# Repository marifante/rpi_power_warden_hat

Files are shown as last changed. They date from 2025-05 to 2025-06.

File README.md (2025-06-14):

# Raspberry Pi Warden Hat

This repository contains the kicad project of Power Warden HAT.

   <div align="center">
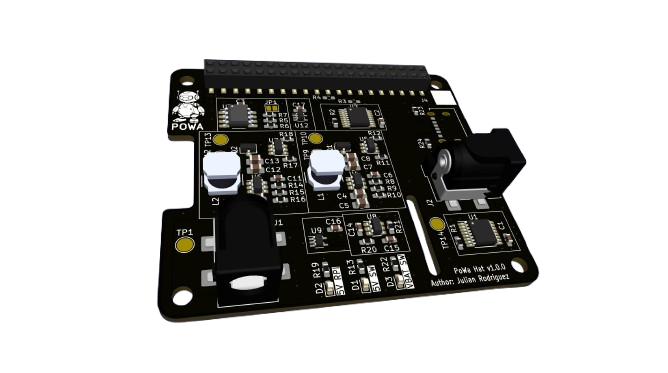
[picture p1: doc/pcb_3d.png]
Power Warden HAT
     
   </div>

## Board description

The HAT is designed to be used with a Raspberry Pi to monitor and control power domains.
It features:

- An individual 5 V power domain.
- An VBAT power domain.
- A dedicated 5 V power supply for the Raspberry Pi.
- An EEPROM to store the HAT configuration.

## Power domains

Each power domain is equipped with a current sensor and an enable input.
The enable input is routed directly to some Raspberry Pi GPIO, allowing the user to control the state of the power domain.
Besides that, the enable input is also controlled by the current sensor, which can disable the power domain quickly in case of over-current.

## 40-pin connector

This HAT is using an SMT 2x20 pin connector for the Raspberry Pi GPIOs. The reasons behind this are:

- This connector has a smaller footprint.
- Enables to only have assembly in one side of the board.
- Allows to use the Raspberry Pi GPIOs without the need to add another header to the board.

In order to connect the HAT to the Raspberry Pi, you need a stacking header.
The [GPIO Stacking Header for Pi A+/B+/Pi 2/Pi3 - Extra-long 2x20 pins from Adafruit industries will do the trick](https://www.adafruit.com/product/2223).

## Software support

There already exists a python library to control the HAT, which can be found at [powa's repository](https://github.com/marifante/powa).

Besides that, there is also a Yocto layer that includes all the necessary software to use the HAT, which can be found at [Power Warden Yocto Layer](https://github.com/marifante/meta-power-warden).

   <div align="center">
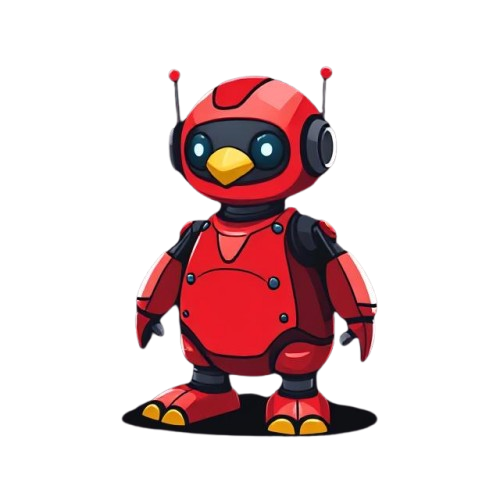
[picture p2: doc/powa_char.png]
Power Warden Character
     
   </div>

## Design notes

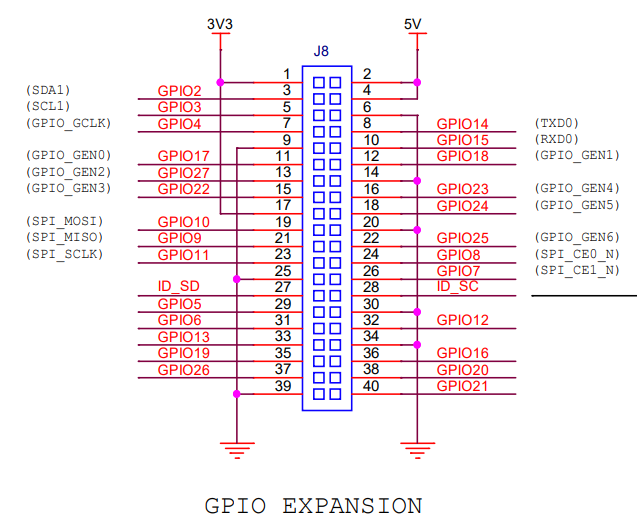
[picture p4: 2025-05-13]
kicad_proj/img/rpi_4_sch_gpio_40_header.png

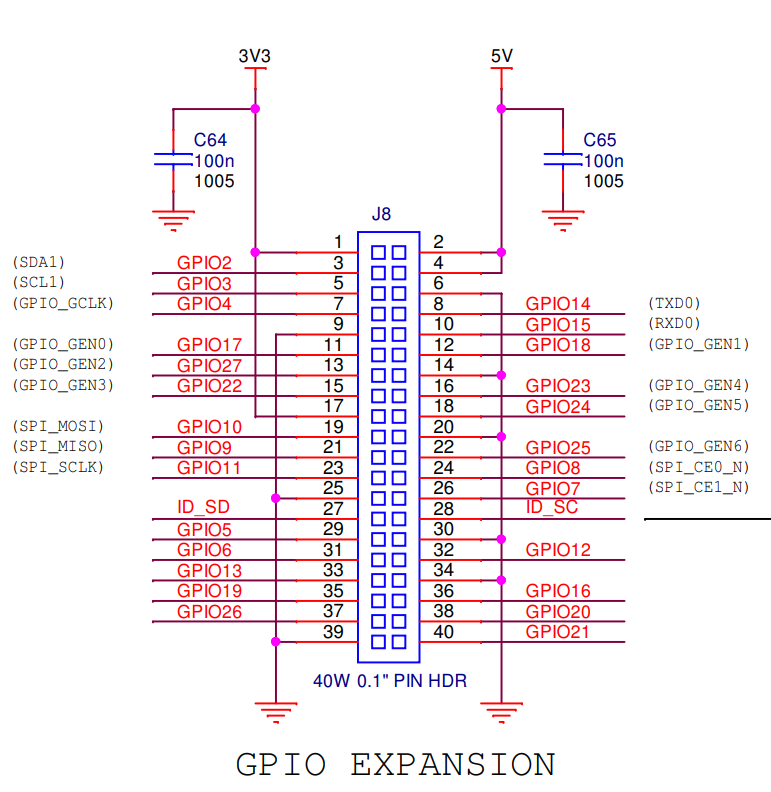
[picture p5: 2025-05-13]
kicad_proj/img/rpi_3_b_sch_gpio_40_header.png

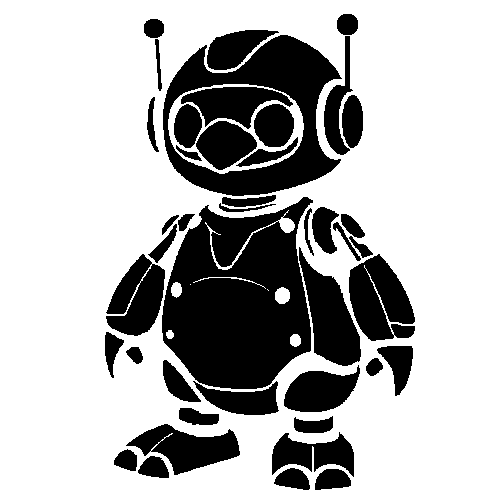
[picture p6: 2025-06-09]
doc/powa_char_monocolor.bmp

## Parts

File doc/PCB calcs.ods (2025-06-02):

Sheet: LM3489MMX = RPI PWR SUPPLY
Datasheet | https://www.ti.com/lit/ds/symlink/lm3489.pdf?HQS=dis-dk-null-digikeymode-dsf-pf-null-wwe&ts=1746998366313
Design parameters
max(I_OUT) [A] | 3
nominal(V_OUT) [V] | 5 |  |  |  |  |  |  |  | 270 | 283.5 | 256.5
nominal(V_IN) [V] | 12
min(V_IN) [V] | 10.8
max(V_IN) [V] | 13.2
Freq [MHz] | 1
1) Inductor ripple curent = delta(i_L)
delta(i_L) [A] | 0.9
Ipeak [A] | 3.795 | "+10% security MARGIN"
2) PMOS initial pick | FDS4435BZ (https://www.digikey.com/en/products/detail/onsemi/FDS4435BZ/1305763)
nominal(V_PGATE_high) [V] | 7 | This does not depends on the transistor. Only on the buck converter IC (LM3489)
min(V_PGATE_high) [V] | 5.8
max(V_PGATE_high) [V] | 8.2
V_DS [V] | 0.1 | (should be pretty small, we could not see it in the plot)
P_MAX [W] | 2.5 | Use this because we will use big polygons to connect it.
RDS_ON @ VGS = -10 V [mOhm] | 15
RDS_ON @ VGS = -5.8 V [mOhm] | 20
RDS_ON worst case [OHM] | 0.02
Also checked and the PMOS will switch with the minimum PMOS gate voltage |  |  | 5.8
3) Pick inductor inductance = L
3.1) First draft of inductance vs duty cycle
V_IN [V] | D | L [uH]
12 | 0.1 | 0.8
12 | 0.2 | 1.5
12 | 0.3 | 2.3
12 | 0.4 | 3.1
12 | 0.5 | 3.8
12 | 0.6 | 4.6
12 | 0.7 | 5.4
12 | 0.8 | 6.1
12 | 0.9 | 6.9
12 | 1 | 7.7
10.8 | 0.1 | 0.6
10.8 | 0.2 | 1.3
10.8 | 0.3 | 1.9
10.8 | 0.4 | 2.5
10.8 | 0.5 | 3.2
10.8 | 0.6 | 3.8
10.8 | 0.7 | 4.4
10.8 | 0.8 | 5.1
10.8 | 0.9 | 5.7
10.8 | 1 | 6.3
13.2 | 0.1 | 0.9
13.2 | 0.2 | 1.8
13.2 | 0.3 | 2.7
13.2 | 0.4 | 3.6
13.2 | 0.5 | 4.5
13.2 | 0.6 | 5.4
13.2 | 0.7 | 6.3
13.2 | 0.8 | 7.2
13.2 | 0.9 | 8.1
13.2 | 1 | 9.0
Target inductance L [uH] | 4.7
3.2) Compute min and max duty cycles for this inductance
V_IN [V] | D [ratio]
12 | 0.613
10.8 | 0.742
13.2 | 0.522
3.3) Pick inductor | HPC 8040NV-4R7M | https://www.digikey.com/en/products/detail/tai-tech-advanced-electronics-co-ltd/HPC-8040NV-4R7M/17835863 | https://mm.digikey.com/Volume0/opasdata/d220001/medias/docus/4803/HPC-BMV-NV%20Series.pdf
R [mOhm] | 19.5
I_MAX [A] | 5.3 | OK: THE INDUCTOR CAN TOLERATE THE MAX CURRENT
4) Feedback pin resistors
VOUT [V] | 5
R2 [kOhm] | R1 [kOhm]
22000 | 66781.2752219532
6) Output capacitor selection (C_OUT)
GRM21BR61E226ME44L
ESR @ 1MHz [Ohm] | 0.002 | https://ds.murata.co.jp/simsurfing/mlcc.html?lcid=en-us&jis=false&md5=0fb4c54c87aec8be024844c7eb6e43f5
ESR @ DC | 2.1
C @ 5V [uF] | 9.96
Compute C_OUT | https://www.ti.com/lit/an/slva477b/slva477b.pdf?ts=1747228739917
delta(IL) [A] | delta(Vout) [mV] | min(COUT) [uF] | delta(VCOUT_RIPPLE) [mV]
0.9 | 25 | 4.5 | 1.8
0.9 | 12.5 | 9 | 1.8
Check output frequency with this ESR
nominal(VHYST) [V] | 0.01
max(VHYST) [V] | 0.02
nominal(VIN - VOUT) [V] | 7
delay [ns] | 90
delay [us] | 0.09
R1 [kOhm] | R2 [kOhm] | max(VOUT_PP) [mV] | VIN [V] | Voltage term [V] | alpha | ESR/Denominador | F [MHz]
66781.2752219532 | 22000 | 80.7102502017756 | 12 | 2.91666666666667 | 4.03551251008878 | 0.00524248902377661 | 0.0152905929860151 | 65.3996873054307
7) Input capacitor selection (C_IN)
V_IN [V] | I_RSM [A] |  | GRM21BR61E226ME44L
12 | 1.68 |  | ESR @ 1MHz [Ohm] | 0.002 | https://ds.murata.co.jp/simsurfing/mlcc.html?lcid=en-us&jis=false&md5=0fb4c54c87aec8be024844c7eb6e43f5
10.8 | 1.73 |  | ESR @ DC | 2.1
13.2 | 1.62 |  | C @ 12V [uF] | 3.8
ESR_CIN [OHM] | P_D_CIN [W]
0.002 | 0.00601851851851852
2.1 | 6.31944444444445
Since "The capacitance value must be selected such that the ripple voltage created by the switch current pulses is less than 10% of the total DC voltage across the capacitor."
delta(V_IN_pp) ratio | 0.01
From https://www.ti.com/lit/an/slyt670/slyt670.pdf?ts=1747148474725
V_IN [V] | D [ratio] | delta(V_IN_pp) [V] | min(C_IN) [uF]
12 | 0.613 | 0.12 | 5.93052930056711
10.8 | 0.742 | 0.108 | 5.3162511542013
13.2 | 0.522 | 0.132 | 5.6705948372615
Capacitors needed in parallel | 2 | Check if we need more than 1 capacitor in parallel because the DC bias drops the capacitance
8) Programming current limit (RADJ) | This will work mostly as a last resource protection.
min(V_IN) [V] | 10.8
R_ADJ_MAX [kOhm] | 1043
I_CL_ADJ [uA] | 3
RDS_ON [OHM] | I_IND_PEAK [A] | RADJ [kOHM]
0.02 | 3.795 | 25.30 | OK: This RADJ is lower than the maximum allowed by the datasheet!
0.015 | 3.795 | 18.98 | OK: This RADJ is lower than the maximum allowed by the datasheet!
Selection of R_ADJ [kOhm] | 24
RDS_ON [OHM] | I_IND_PEAK [A]
0.015 | 4.8
0.02 | 3.6
9) Catch diode selection
D | I_D_AVE (A)
0.61 | 1.16
0.74 | 1.29
0.52 | 5.73
Selection | SRM84ALF_R1_00001 | https://www.digikey.com/en/products/detail/panjit-international-inc/SRM84ALF-R1-00001/15801087
10) Re-check PMOS selection
toff [ns] | 48
ton [ns] | 20
ton_rise [ns] | 12 | OK: The turn on rise is less than 100, which is the max recommended in the datasheet
RDSON [Ohm] | 0.02
V_IN [V] | D [ratio] | PD_switch [W]
12 | 0.613 | 1.334 | OK: The PMOS will be fine with the max power that can be dissipated
10.8 | 0.742 | 1.235 | OK: The PMOS will be fine with the max power that can be dissipated
13.2 | 0.522 | 1.440 | OK: The PMOS will be fine with the max power that can be dissipated

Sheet: TPS563200DDCR
Datasheet | https://www.ti.com/lit/ds/symlink/tps563200.pdf?ts=1747290619863
Design parameters
max(I_OUT) [A] | 3
nominal(V_OUT) [V] | 5
nominal(V_IN) [V] | 12
min(V_IN) [V] | 10.8
max(V_IN) [V] | 13.2
Freq [kHz] | 650 | (fixed by the IC)
1) Feedback resistors
R3 [kOhm] | R2 [kOhm] |  | R3 [kOhm] | R2 [kOhm]
10 | 55 | => Use recommended | 10 | 54.9
2) Inductor selection
Pick inductor | HPC 6045NV-4R7M | https://www.digikey.com/en/products/detail/tai-tech-advanced-electronics-co-ltd/HPC-6045NV-4R7M/17835507
L [uH] | 4.7 | recommended |  |  |  | GRM21BR61E226ME44L
R [mOhm] | 26
I_MAX [A] | 4
max(V_IN) [V] | V_OUT [V] | delta(I_pp) [A] | I_peak [A] | I_L_rms [A]
13.2 | 5 | 1.02 | 3.508 | 3.014 | OK: the inductor can handle this current
3) Output capacitor selection
GRM21BR61E226ME44L
ESR @ 1MHz [Ohm] | 0.002
ESR @ DC | 2.1
C @ 5V [uF] | 9.96
V_IN [V] | I_CO_rms [A]
12 | 0.2756
10.8 | 0.2537
13.2 | 0.2935
Will not raise even 1 C with that current

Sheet: TPS22810
datasheet | https://www.ti.com/lit/ds/symlink/tps22810.pdf?HQS=dis-dk-null-digikeymode-dsf-pf-null-wwe&ts=1748266268743
10.5.2.1 | Shutdown sequencing during unexpected power loss
Desired fall time [ms] | 20
CL [uF] | Vin [V] | Vcap [V] | ln(Vin/Vcap) | RQOD [Ohm]
22 | 12 | 1.2 | 2.30258509299405 | 394.813165366593
22 | 10.8 | 1.08 | 2.30258509299405 | 394.813165366593
22 | 13.2 | 1.32 | 2.30258509299405 | 394.813165366593
RPD @ 12 V [Ohm] | 250
REXT | 144.813165366593
9.3.4 | Rise time
Ct [pF] | 4700
Slew Rate [V/us] | 0.00991914893617021
Vin [V] | Rise Time [us]
12 | 1209.78120978121
10.8 | 1088.80308880309
13.2 | 1330.75933075933
10.5.2.3 | Inrush current
Vin [V] | dVOUT [V]
12 | 9.6
10.8 | 8.64
13.2 | 10.56

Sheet: Schematic pre layout check
Sheet | Designator | SCH connection checked | Symbol checked | Symbol – footprint assignation checked | Footprint checked | Date
Root | J1 | Yes | Yes | Yes | Yes | 05/28/25
 | J2 | Yes | Yes | Yes | Yes | 05/28/25
 | J3 | Yes | Yes | Yes | Yes | 05/31/25
dc_dc_vbat_5v | U5 | Yes | Yes | Yes | Yes | 05/31/25
 | C9, C10, C12 & C13 | Yes | Yes | Yes | Yes | 05/31/25
 | R13 | Yes | Yes | Yes | Yes | 05/31/25
 | R14 | Yes | Yes | Yes | Yes | 05/31/25
 | L2 | Yes | Yes | Yes | Yes | 05/31/25
 | U2 | Yes | Yes | Yes | Yes | 06/02/25
 | Q1 | Yes | Yes | Yes | Yes | 06/02/25
rpi | J4 | Yes | Yes | Yes | Yes | 06/01/25
 | U3 | Yes | Yes | Yes | Yes | 06/01/25
and | U7 | Yes | Yes | Yes | Yes | 06/02/25
load_switch | U6 | Yes | Yes | Yes | Yes | 06/02/25
current_sensor | U1 | Yes | Yes | Yes | Yes | 06/02/25
Those designators were changed on 06/02/2025 to have a more ordered schematic with incremental designator numbers.

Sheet: Sheet5
A | C | B
7.6 | 2.54 | 2.53
B | L | D | X
2.53 | 1.78 | 0.51 | 0.24
D | X | L | Oi
0.51 | 0.24 | 1.78 | 1.64
P | N | T | H | T-H | (T-H)/2
2.54 | 20 | 48.26 | 45.72 | 2.54 | 1.27
L | G | P
6.5 | 2.2 | 2.15 | 2.175

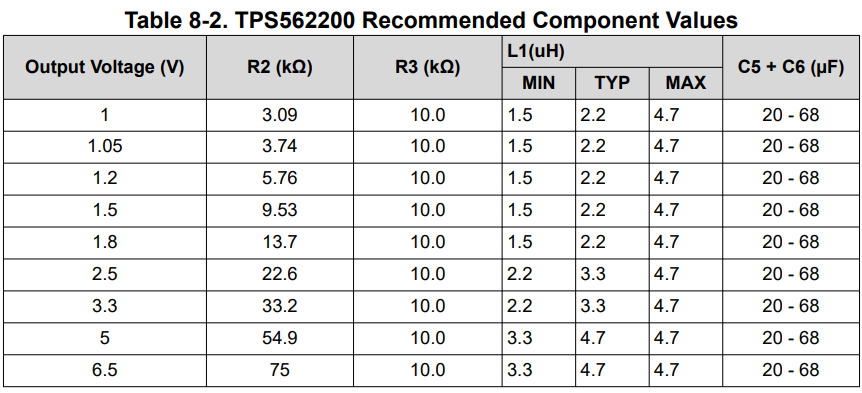
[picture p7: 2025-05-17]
kicad_proj/img/tps_56x200_recommended_components.png

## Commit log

2025-05-13 wip: schematic
    [dc_dc_vbat_5v.kicad_sch, power.kicad_sch, power_sensor.kicad_sch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]
2025-05-17 feat: put USB A receptacle to deliver power, have progress in INA260 and place test poitns
    [dc_dc_vbat_5v.kicad_sch, power_sensor.kicad_sch, rpi.kicad_sch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]
2025-05-27 add a switched vbat feature
    [current_sensor.kicad_sch, dc_dc_vbat_5v.kicad_sch, load_switch.kicad_sch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]
2025-05-27 re-annotate schematic, add leds to power supply outputs and add connector for VBAT switched load
    [current_sensor.kicad_sch, dc_dc_vbat_5v.kicad_sch, load_switch.kicad_sch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]
2025-05-28 add RPi HAT eeprom to schematic
    [dc_dc_vbat_5v.kicad_sch, rpi.kicad_sch, rpi_power_warden_hat.kicad_sch]
2025-05-28 add: raspberry pi footprint
    [rpi.kicad_sch]
2025-05-28 re-annotate schematic
    [current_sensor.kicad_sch, dc_dc_vbat_5v.kicad_sch, load_switch.kicad_sch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]
2025-05-31 add and gate in swiched power supplies enable
    [and.kicad_sch, current_sensor.kicad_sch, dc_dc_vbat_5v.kicad_sch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]
2025-05-31 move docs to a dir in the root called docs/
    [PCB calcs.ods]
2025-05-31 refactor: delete multiple dirs
    [and.kicad_sch, current_sensor.kicad_sch, dc_dc_vbat_5v.kicad_sch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]
2025-06-01 checked root, dc dc and rpi sheets
    [and.kicad_sch, dc_dc_vbat_5v.kicad_sch, load_switch.kicad_sch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]
2025-06-01 update PCB calcs doc (tracking of checking updated)
    [PCB calcs.ods]
2025-06-02 checked all the schematics
    [current_sensor.kicad_sch, dc_dc_vbat_5v.kicad_sch, load_switch.kicad_sch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]
2025-06-02 configure BOM output
    [rpi_power_warden_hat.csv]
2025-06-02 add ideal diode to 5v power supply
    [PCB calcs.ods, dc_dc_vbat_5v.kicad_sch]
2025-06-02 remove whitespaces from some resistors's mpn, add mpn to pnp in zvd symbol and regenerate bom
    [dc_dc_vbat_5v.kicad_sch, rpi.kicad_sch, rpi_power_warden_hat.csv]
2025-06-02 run ERC and fix some errors (no critical errors, mostly associated to raspberry pi connectors not connected and with not NC flag
    [rpi.kicad_sch, rpi_power_warden_hat.kicad_sch]
2025-06-02 add footprint to j5
    [rpi.kicad_sch]
2025-06-02 fix: rpi footprint (board outline was not being done correctly)
    [rpi_power_warden_hat.kicad_pcb]
2025-06-02 loaded jlcpcb design constraints
    [rpi_power_warden_hat.kicad_pcb]
2025-06-02 progress a bit with the placement an replace 5 v buck converter L for a smaller one
    [PCB calcs.ods, dc_dc_vbat_5v.kicad_sch, rpi_power_warden_hat.kicad_pcb]
2025-06-02 finish placement
    [current_sensor.kicad_sch, rpi.kicad_sch, rpi_power_warden_hat.kicad_pcb]
2025-06-02 progress with layout
    [rpi_power_warden_hat.kicad_pcb]
2025-06-07 feat: replace tht jumper by as solder bridge. feat: progress with layout.
    [rpi.kicad_sch, rpi_power_warden_hat.kicad_pcb]
2025-06-09 fix: all DRCs in PCB. First layout is done.
    [rpi_power_warden_hat.kicad_pcb]
2025-06-09 add powa logo image
    [rpi_power_warden_hat.kicad_pcb]
2025-06-09 fix: DRCs due to logo
    [rpi_power_warden_hat.kicad_pcb]
2025-06-09 add teardrops
    [rpi_power_warden_hat.kicad_pcb]
2025-06-09 re-touch a little bit the layout in 5V and gate
    [rpi_power_warden_hat.kicad_pcb]
2025-06-09 update BOM (changed inductor)
    [rpi_power_warden_hat.csv]
2025-06-09 modify general soldermask expansion to 0 and generate outputs.
    [rpi_power_warden_hat-B_Cu.gbl, rpi_power_warden_hat-B_Mask.gbs, rpi_power_warden_hat-B_Paste.gbp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]
2025-06-09 generate pick and place
    [rpi_power_warden_hat-bottom-pos.csv, rpi_power_warden_hat-top-pos.csv]
2025-06-09 fix: replace some components out of stock in lcsc
    [dc_dc_vbat_5v.kicad_sch, load_switch.kicad_sch, rpi.kicad_sch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]
2025-06-10 replaced almost all the components out of stock (only tensility connectors: USB and jack needs to be replaced)
    [and.kicad_sch, rpi_power_warden_hat.csv, rpi_power_warden_hat.kicad_pcb]
2025-06-12 changed usb A for an usb C with more stock
    [and.kicad_sch, rpi_power_warden_hat.kicad_pcb, rpi_power_warden_hat.kicad_sch]
2025-06-14 replace DC jack for one with stock
    [rpi_power_warden_hat.kicad_pcb, rpi_power_warden_hat.kicad_sch]
2025-06-14 remove outputs
    [rpi_power_warden_hat-B_Cu.gbl, rpi_power_warden_hat-B_Mask.gbs, rpi_power_warden_hat-B_Paste.gbp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]
2025-06-14 delivered version
    [rpi_power_warden_hat-B_Cu.gbl, rpi_power_warden_hat-B_Mask.gbs, rpi_power_warden_hat-B_Paste.gbp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]
